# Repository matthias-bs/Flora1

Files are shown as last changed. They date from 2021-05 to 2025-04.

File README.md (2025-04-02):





# flora1 &mdash; Raspberry Pi Irrigation System

flora-1_188x300

## Features
* Plant status monitorig via [Xiaomi Mi Flora Plant Sensor MQTT Client/Daemon](https://github.com/ThomDietrich/miflora-mqtt-daemon)
* Tank low / tank empty status monitoring with XKC-Y25-T12V (Non-Contact Liquid Level Sensor)
* Pump control (12 Volts) with [Infineon BTS621L1](https://www.infineon.com/cms/en/product/power/smart-low-side-high-side-switches/high-side-switches/classic-profet-12v-automotive-smart-high-side-switch/bts621l1-e312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) (Smart Two-Channel High-Side Power Switch)
* Automatic and manual irrigation control with one or two pumps
* Controlling and monitoring via MQTT 

## Dashboard with [IoT MQTT Panel](https://snrlab.in/iot/iot-mqtt-panel-user-guide) (Example)

IoTMQTTPanel_Flora-Control_400x580

## Why is it called _flora1_?

Because _flora2_ is already in the works!

## Notes

### Starting with Linux systemd service

#### Issue

After updating from *Raspbian Buster* to Raspberry Pi OS *Debian Bookworm*, the service wouln't start. The reason was that some code in `lgpio` used for accessing GPIO pins tries to write into the working directory (see https://github.com/gpiozero/gpiozero/issues/1106), which was not permitted.

#### Workaround

* Split WorkingDirectory and RuntimeDirectory (see [09_software/template.service](https://github.com/matthias-bs/Flora1/blob/2-starting-via-linux-systemd-service-fails/09_software/template.service))
  * WorkingDirectory=/var/run/flora/
  * RuntimeDirectory=/opt/flora
* Create `/var/run/flora` at startup (if will not persist if created manually!)
  * See https://serverfault.com/questions/824393/var-run-directory-creation-even-though-service-is-disabled
  * In `/usr/lib/tmpfiles.d/var.conf`:<br>
    add<br>
    `d /var/run/flora 0770 root daemon -`

----

## Disclaimer and Legal

> *Xiaomi* and *Mi Flora* are registered trademarks of *BEIJING XIAOMI TECHNOLOGY CO., LTD.*
>
> This project is a community project not for commercial use.
> The authors will not be held responsible in the event of device failure or withered plants.
>
> This project is in no way affiliated with, authorized, maintained, sponsored or endorsed by *Xiaomi* or any of its affiliates or subsidiaries.

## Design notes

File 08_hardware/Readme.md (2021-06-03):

# flora1 Hardware

Selecting a Raspberry Pi version
---------------------------------
My initial plan was to re-use an old *Raspberry Pi Model B* (which is more than adequate regarding speed and memory), but the WiFi connection via USB dongle proved to be unreliable. Restarting the driver via a script called from a cron-job did not help either.
Moving to a *Raspberry Pi 3 Model A+* solved this issue. This version was selected as a good compromise between power consumption, size, price and processing power.

Connector J4
-------------
Due to the initial plan using a *Raspberry Pi Model B*, a 26-pin header was used. For changing to a *Raspberry Pi 3*, a ribbon cable with a 26-pin-connector on one side and a 40-pin-connector on the other side was used. **It is highly recommended to use a 40-pin header in new designs!**

High Side Driver Infineon BTS621L1
-----------------------------------
The driver works fine, but the device package seems to be outdated (and is not very practical for breadboard designs). For a redesign, I used the [Infineon BTS117](https://www.infineon.com/cms/en/product/power/smart-low-side-high-side-switches/low-side-switches/classic-hitfet-24v/bts117/) *"N channel vertical power FET in Smart SIPMOS® technology"*. The latter is a single channel low-side switch and provides less diagnostic functions, but is available in a handy TO220-3 package. 

Breadboard vs. printed circuit board
-------------------------------------
It's a matter of taste, but next time I would rather design a printed circuit board and have it made by a PCB service. In the original design an *RND 455-00555* prototype board (67.8x86.9mm) by *RND Components* was used. 

Barometric Pressure Sensor connector (J1)
------------------------------------------
For new designs, I prefer a *Bosch BME280* instead of the *NXP MPL115*. The *BME280* provides temperature, humidity and barometric pressure with (in my opinion) excellent specifications.

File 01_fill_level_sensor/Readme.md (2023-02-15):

# flora1 Tank Level Sensors

[DFRobot SEN0204 Non-contact Liquid Level Sensor XKC-Y25-T12V](https://wiki.dfrobot.com/Non-contact_Liquid_Level_Sensor_XKC-Y25-T12V_SKU__SEN0204)

Or use your favourite search engine to find the manual/"datasheet" and a supplier for the sensor **XKC Y25 T12V**. The original manufacturer seems to be hard to find...

XKC_Y25_T12V Front View

XKC_Y25_T12V Front View

XKC_Y25_T12V Back View
(I am using velcro tape to attach the sensors to the tank.)

XKC_Y25_T12V Back View

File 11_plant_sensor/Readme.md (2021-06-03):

# flora1 Plant Sensors

Please refer to https://xiaomi-mi.com/home/user-manuals/ and search for *Huahuacacao Flower Care Smart Monitor* - or use your favourite search engine with the keywords *Mi Flora Plant Sensor* or *Mi Flora Flower Care* for manual/datasheet.

Mi Flora Plant Sensor

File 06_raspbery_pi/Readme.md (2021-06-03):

# flora1 Raspberry Pi

[Raspberry Pi 3 Model A+](https://www.raspberrypi.org/products/raspberry-pi-3-model-a-plus/)

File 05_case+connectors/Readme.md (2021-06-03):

# flora1 Case and Connectors

    | Pos. | Part                                         | Description                        | Comments                         |
    |------|----------------------------------------------|------------------------------------|----------------------------------|
    |    1 | BOPLA EM 238 F                               | Case                               | lots of space for add-ons...     |
    |      | (Series Euromas II, 160 x 120 x 92 mm, IP65) |                                    |                                  |
    | ---- | -------------------------------------------- | ---------------------------------- | -------------------------------- |
    |    2 | Raspberry Pi Sticker                         |                                    | not strictly necessary, but cool |
    | ---- | -------------------------------------------- | ---------------------------------- | -------------------------------- |
    |    3 | GORE PMF 100391 / Wiska EVPS 12 HF           | Vent, M12                          | optional                         |
    |      | (or similar) with M12 Nut                    |                                    |                                  |
    | ---- | -------------------------------------------- | ---------------------------------- | -------------------------------- |
    |    4 | 2x Cable Gland M12 with M12 Nut              | for Power Supply + Pump            |                                  |
    | ---- | -------------------------------------------- | ---------------------------------- | -------------------------------- |
    |    5 | 2x Barrel Jack 2.1mm x 5.5mm with Pigtail    | for Power Supply + Pump            | preferably with sleeve           |
    | ---- | -------------------------------------------- | ---------------------------------- | -------------------------------- |
    |    6 | 2x Pöppelmann Kapsto GPN 305 GV 12           | Sealing Plugs for Barrel Jacks     | optional                         |
    | ---- | -------------------------------------------- | ---------------------------------- | -------------------------------- |
    |    7 | 2x Lumberg Quicklock 0270-04 /               | Quicklock chassis sockets, IP67,   |                                  |
    |      | Lutronic Quicklock 2320 04 T12CB100          | Size 12 - for Fill Level Inputs    |                                  |
    | ---- | -------------------------------------------- | ---------------------------------- | -------------------------------- |
    |    8 | 2x Lumberg Quicklock 0250-04 /               | Quicklock plug with locking latch, |                                  |
    |      | Lutronic 2350 04 T06CB T                     | IP67, Size 12 - for Level Sensors  |                                  |
    |------|----------------------------------------------|------------------------------------|----------------------------------|

flora-1_378x600      flora-2_378x600

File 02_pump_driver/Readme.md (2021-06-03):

# flora1 Pump Driver

[Infineon BTS621L1](https://www.infineon.com/cms/en/product/power/smart-low-side-high-side-switches/high-side-switches/classic-profet-12v-automotive-smart-high-side-switch/bts621l1-e312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) "High side power switch with integrated vertical power FET".
The TO220-7 package version seems to be discontinued.

For a redesign, I used the [Infineon BTS117](https://www.infineon.com/cms/en/product/power/smart-low-side-high-side-switches/low-side-switches/classic-hitfet-24v/bts117/) "N channel vertical power FET in Smart SIPMOS® technology". The latter is a single channel low-side switch and provides less diagnostic functions.

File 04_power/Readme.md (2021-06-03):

# flora1 Power

**Note: Please ensure that your AC-DC-adaptor's specifications (IP class) meet your environmental conditions!** 

AC-DC Wall mount adaptor 12V/3A: [Mean Well GS36E12-P1J](https://www.meanwell-web.com/en-gb/ac-dc-wall-mount-adaptor-output-12vdc-at-3a-input-gs36e12--p1j) **_For indoor use only!_** 

DC-DC-Converter 6-40V to 5V/3A: [REG5V3A](https://www.berrybase.de/en/raspberry-pi/raspberry-pi-computer/power-supply/built-in-industrial-power-supply-modules/netzteilmodul-6-40v-5v/3a-mit-2x-usb-ausgang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)

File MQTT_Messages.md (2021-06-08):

# flora1 MQTT Messages

```
MQTT subscriptions:
     <base_topic_sensors>/<sensors>{}      (JSON encoded data from Miflora MQTT Daemon)
     <base_topic>/man_report_cmd           (-)
     <base_topic>/man_irr_cmd              (1|2)                         1: pump #1 / 2: pump #2
     <base_topic>/man_irr_duration_ctrl    (<seconds>)
     <base_topic>/auto_report_ctrl         (0|1)
     <base_topic>/auto_irr_ctrl            (0|1)

MQTT publications:
     <base_topic>/status                   (online|offline|idle|dead$)
     <base_topic>/man_irr_stat             (0|1)
     <base_topic>/man_irr_duration_stat    (<seconds>
     <base_topic>/auto_report_stat         (0|1)
     <base_topic>/auto_irr_stat            (0|1)
     <base_topic>/tank                     (0|1|2)                        0: empty / 1: low / 2: o.k.

$ via LWT
```

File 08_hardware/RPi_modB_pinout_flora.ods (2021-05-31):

Raspberry Pi Model B Port 1 Pinout
MPL115_VDD |  | 3V3 | 1 | 2 | +5V
 | I2C_SDA | GPIO2 | 3 | 4 | +5V |  | XKC-Y25-NPN_VCC
 | I2C_SCL | GPIO3 | 5 | 6 | GND |  | MPL115_GND
 |  | GPIO4 | 7 | 8 | GPIO14 | UART_TXD
PUMP_GND |  | GND | 9 | 10 | GPIO15 | UART_RXD
 | UART_RTS | GPIO17 | 11 | 12 | GPIO18 | PWM | (SENSOR_PWR)
PUMP_OUT |  | GPIO27 | 13 | 14 | GND |  | XKC-Y25-NPN_GND
PUMP_STATUS |  | GPIO22 | 15 | 16 | GPIO23 |  | XKC-Y25-NPN_LOW
 |  | 3V3 | 17 | 18 | GPIO24 |  | XKC-Y25-NPN_EMPTY
MPL115_PWR | SPI_MOSI | GPIO10 | 19 | 20 | GND
MPL115_SDO | SPI_MISO | GPIO9 | 21 | 22 | GPIO25
MPL115_SCK | SPI_CLK | GPIO11 | 23 | 24 | GPIO8 | SPI_CE0 | MPL115_CSN
 |  | GND | 25 | 26 | GPIO7 | SPI_CE1

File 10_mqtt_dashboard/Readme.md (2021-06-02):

# Set up *IoT MQTT Panel* from configuration file

You can either edit the provided [JSON configuration file](https://github.com/matthias-bs/Flora1/blob/main/10_mqtt_dashboard/IoTMQTTPanel_Example.json) before importing it or import it as-is and make the required changes in *IoT MQTT Panel*. Don't forget to add the broker's certificate if using Secure MQTT! (in the App: *Connections -> Edit Connections: Certificate path*.)

The dashboard will look like this:
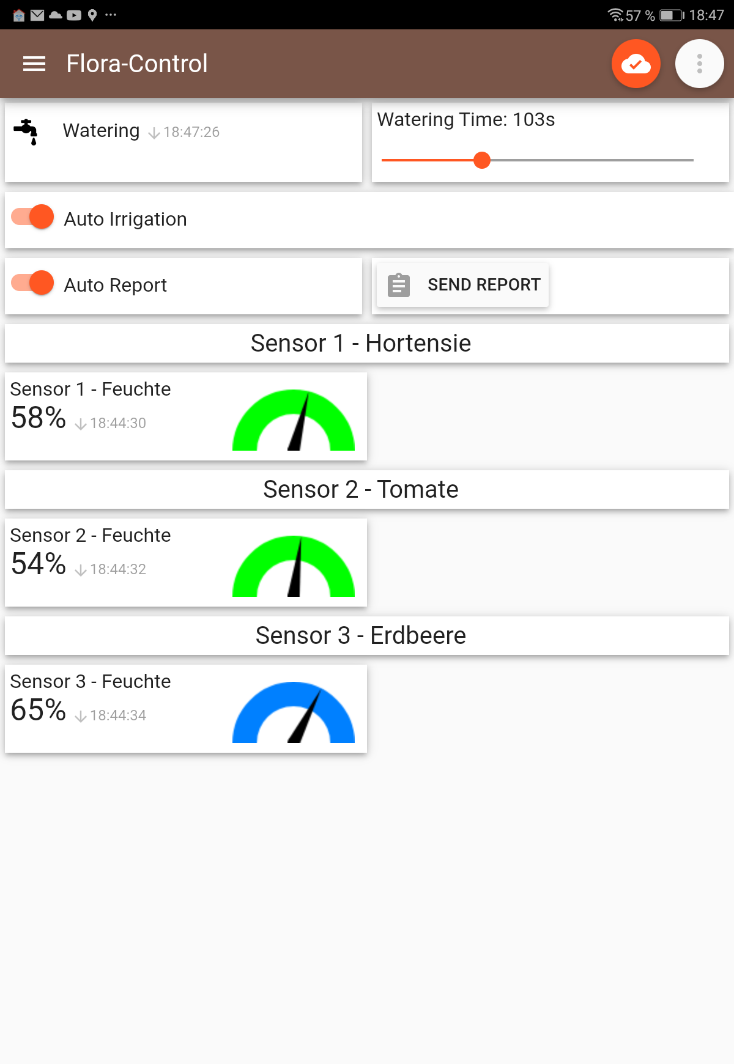
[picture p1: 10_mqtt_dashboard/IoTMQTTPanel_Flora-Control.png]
IoTMQTTPanel - Flora-Control


----
**Install _IoT MQTT Panel_ on your Android device**
  
  see [IoT MQTT Panel](https://snrlab.in/iot/iot-mqtt-panel-user-guide)

----
**Editing [IoTMQTTPanel_Example.json](https://github.com/matthias-bs/Flora1/blob/main/10_mqtt_dashboard/IoTMQTTPanel_Example.json)**

At the beginning, replace the dummy IP address *123.345.678* and port *8883* by your MQTT broker's IP address/hostname and port, change *Your_Client_ID* and *Your_MQTT_Connection* as needed:
```
[...]
"connections":[{"autoConnect":true,"host":"123.345.678","port":8883,"clientId":"Your_Client_ID","connectionName":"Your_MQTT_Connection"
[...]
```

At the end, change *Your_Username* and *Your_Password* as needed:
```
[...]
"username":"Your_Username","password":"Your_Password"
[...]
```

----
**Changing example configuration in _IoT MQTT Panel_**

**Edit _Connection Name_, _Client ID_ and _Broker_:**
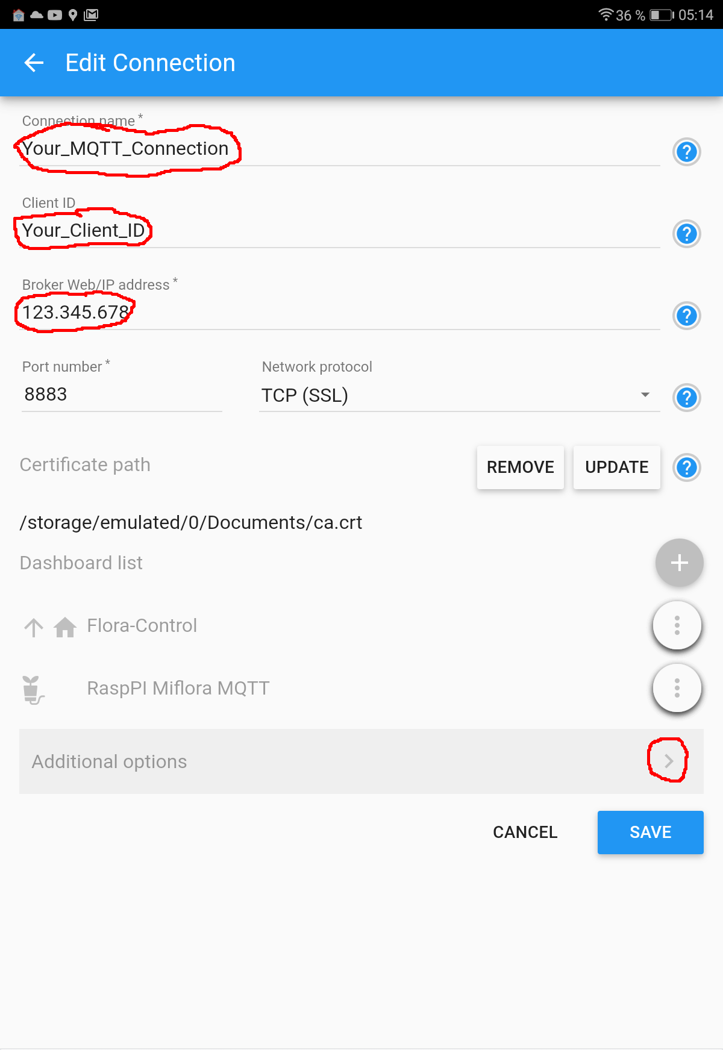
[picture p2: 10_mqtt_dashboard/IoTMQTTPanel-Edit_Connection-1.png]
Edit Connection Name, Client ID and Broker


**Edit _Username_ and _Password_:**
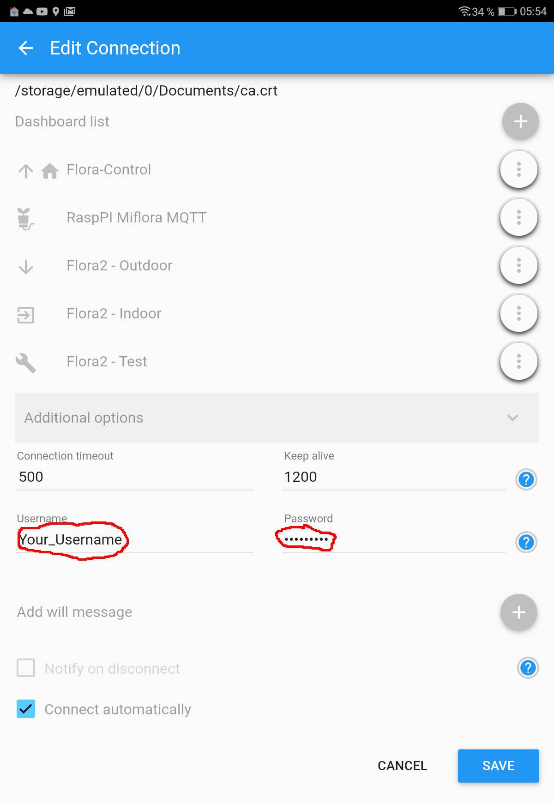
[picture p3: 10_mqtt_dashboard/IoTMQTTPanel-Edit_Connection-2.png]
Edit Username and Password


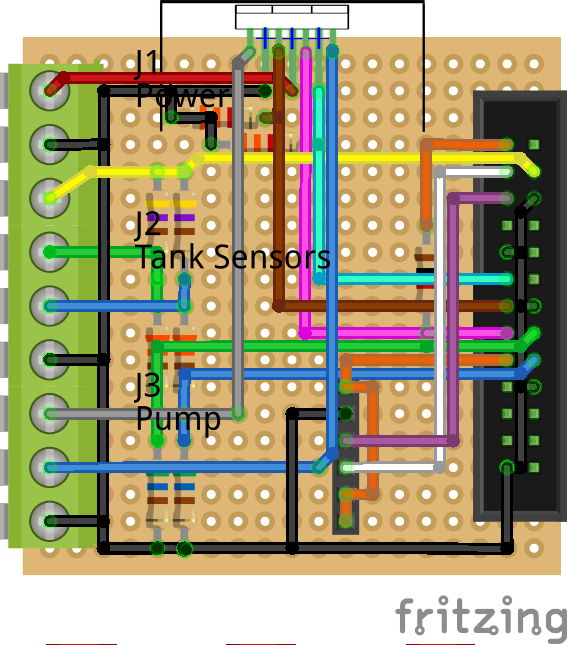
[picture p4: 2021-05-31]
08_hardware/flora_breadboard_rev05_board.png

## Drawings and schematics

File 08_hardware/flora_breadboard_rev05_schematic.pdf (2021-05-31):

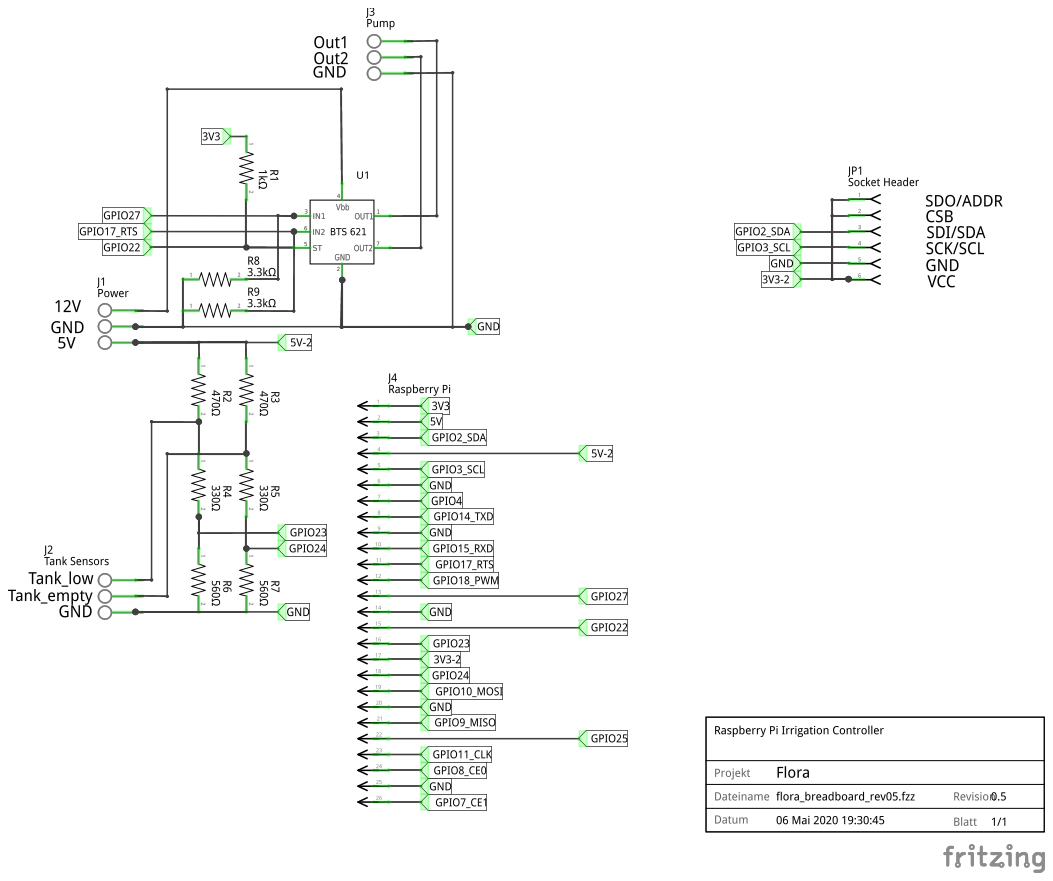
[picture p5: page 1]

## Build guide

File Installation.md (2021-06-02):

# flora1 Software Installation

----
**Overview**

1. Raspberry Pi OS Installation
2. Mosquitto MQTT-Broker Installation and Configuration
3. miflora-mqtt-daemon Installation
4. Optional: Configure Raspberry Pi with static IP address
5. Optional: Set up port forwarding in your router to access your MQTT broker from internet
6. flora1 Installation and Configuration

----
**1. Raspberry Pi OS Installation / Update**

Please refer to https://www.raspberrypi.org/software/.

If you want to use an existing installation, an update might be a good idea:
```
$ sudo apt-get update
$ sudo apt-get upgrade
```
----
**2. Mosquitto MQTT-Broker Installation and Configuration**

Please refer to https://github.com/eclipse/mosquitto for details.

Installation:
```
$ sudo apt-get install -y mosquitto mosquitto-clients
```

Excellent resources on MQTT and Mosquitto:
* http://www.steves-internet-guide.com
* https://www.hivemq.com/mqtt-essentials/

How to set up security mechanisms:
* http://www.steves-internet-guide.com/mqtt-security-mechanisms/
* http://www.steves-internet-guide.com/mqtt-username-password-example/
* http://www.steves-internet-guide.com/mosquitto-tls/

The [MQTT-Explorer](https://github.com/thomasnordquist/MQTT-Explorer) is very useful for testing.

----
**3. miflora-mqtt-daemon Installation**

Please refer to https://github.com/ThomDietrich/miflora-mqtt-daemon.

For compatibility with Flora1, set `reporting_method = mqtt-json` in the **miflora-mqtt-daemon** `config.ini`.

----
**4. Optional: Configure Raspberry Pi with static IP address**

Example `/etc/dhcpcd.conf`:
```
[...]
interface wlan0
static ip_address=192.168.0.10/24
static routers=192.168.0.1
static domain_name_servers=192.168.0.1
```
In this example, the Raspberry gets the private IP Address `192.168.0.10` and the router/DNS has the private IP address ```192.168.0.1```.

----
**5. Optional: Set up port forwarding in your router to access your MQTT broker from the Internet**

***Please refer to your router's documentation and make sure to maintain security!***
***It is highly recommended to allow only Secure MQTT (MQTT over TLS, port 8883) forwarding.***

----
**6. flora1 Installation and Configuration**

Install Python 3 (should already been done in step 3):
```
$ sudo apt install git python3 python3-pip
```

Copy all source files from https://github.com/matthias-bs/Flora1/tree/main/09_software to `/opt/flora`.
```
$ cd /opt/flora
$ sudo cp config.ini.dist config.ini
```
Edit `config.ini` as required. (e.g. ```sudo nano config.ini```) 

Flora1 needs access to GPIO ports to monitor the tank level and and to control the pump.

```$ sudo adduser daemon gpio```

Test your setup / ```config.ini```:

```python3 flora.py```

If everything works as desired: Congratulations!

Now set up flora to run in daemon mode:
```
$ sudo cp /opt/flora/template.service /etc/systemd/system/flora.service
$ sudo systemctl daemon-reload
$ sudo systemctl start flora.service
$ sudo systemctl status flora.service
$ sudo systemctl enable flora.service
```

If needed, check status/error messages in ```/var/log/syslog```.

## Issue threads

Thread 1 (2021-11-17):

Alert handling for empty tank does not work properly

matthias-bs, 2021-11-17:
**Describe the bug**
Email status reports due to **tank empty alert** are sent repeatedly in short intervals , even if alert handling has been set as follows in _config.ini_:
```
# alert handling modes:
[...]
# 1 - immediate alert, only once
[...]
e_tank_empty = 1
```
A similar issue was never observed for **tank low alert** with the same configuration.

**To Reproduce**
Set `e_tank_empty = 1` in _config.ini_. Drain the tank until empty level is detected.

**Expected behavior**
Email status report due to empty tank should be sent only once.

**Additional context**
Outside temperatures around 7-9°C might have influence on the level sensor's trigger level.

matthias-bs, 2021-11-17:
Possible cause: Tank level sensor output might toggle between active and inactive state.

matthias-bs, 2025-04-02:
Alert mechanism has been removed.

Closed 2025-04-02.

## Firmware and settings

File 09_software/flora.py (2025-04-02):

#!/usr/bin/env python3
# -*- coding: utf-8 -*-

###############################################################################
# flora.py
# Plant monitoring and irrigation system using Raspberry Pi
#
# - based on data provided by Mi Flora Plant Sensor MQTT Client/Daemon
# - controls water pump for irrigation
# - monitors water tank - two levels, low and empty
# - provides control/status via MQTT
#
# MQTT subscriptions:
#     <base_topic_sensors>/<sensors>{}      (JSON encoded data)
#     <base_topic>/man_irr_cmd              (1|2)
#     <base_topic>/man_irr_duration_ctrl    (<seconds>)
#     <base_topic>/auto_irr_ctrl            (0|1)
#
# MQTT publications:
#     <base_topic>/status                   (online|offline|idle|dead$)
#     <base_topic>/man_irr_stat             (0|1)
#     <base_topic>/man_irr_duration_stat    (<seconds>)
#     <base_topic>/auto_irr_stat            (0|1)
#     <base_topic>/tank                     (0|1|2)
#
# $ via LWT
#
# created: 02/2020
#
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
# History:
#
# 20200226 Tank level sensor input working
# 20200302 Config file reading implemented
# 20200304 MQTT client for plant sensor data working
# 20200309 E-mail report implemented, pump control via MQTT message working
# 20200325 Sending e-mail report based on sensor/plant data implemented
# 20200421 Specific irrigation time for automatic/manual mode added
#          MQTT feedback messages for manual irrigation time setting added
#          Handling of sensor time-out added
# 20200428 Added switching auto reporting and auto irrigation on/off via MQTT
# 20200502 Rev. 1.0, Initial release
# 20200504 Added night mode
# 20210105 Fixed manual irrigation
#          Messages were queued while irrigation was already in progress,
#          which led to multiple irrigation cycles where only one was desired.
#          Added message 'man_irrigation_status'
# 20210106 Code cleanup
#          Added tank object as parameter to Pump class constructor -
#          the mapping between pump and tank will never change during run time
# 20210116 Major refactoring and switch to object oriented implementation
#          Functional improvement of E-mail reporting
# 20210117 Split source file into multiple modules
#          Replaced set-/get-methods by properties
# 20210118 Renamed MQTT topics
# 20210602 Added MQTT status message and last will
#          Added MQTT tank message
# 20210608 Added support of 2nd pump
# 20230204 Coding style improvements and bugfixes (with pylint)
# 20250401 Removed auto_report/man_report and alert handling
# 20250401 Removed email support, added JSON output for MQTT
#          Added publish_discovery_sensor() for Home Assistant
#
# To Do:
# - compare light value against daily average
# - add humidity/barometric pressure sensor
#
###############################################################################

import locale
import sys
import argparse
import os.path
import json
import ssl
from time import sleep
from configparser import ConfigParser
import paho.mqtt.client as mqtt
from colorama import init as colorama_init
from colorama import Fore, Style
from ppretty import ppretty #for debugging only

# Flora specific modules
from settings import Settings, DEBUG, VERBOSITY, PROJECT_NAME, PROJECT_VERSION,\
                     PROJECT_BUILD, PROJECT_URL, GPIO_TANK_SENS_LOW, GPIO_TANK_SENS_EMPTY,\
                     GPIO_PUMP_POWER, GPIO_PUMP_STATUS, PROCESSING_PERIOD, MESSAGE_TIMEOUT,\
                     BATT_LOW, PUMP_BUSY_MAN
from print_line import print_line, sd_notifier
from gpio import GPIO
from sensor import Sensor
from tank import Tank
from pump import Pump
from irrigation import Irrigation
from report import Report

# Options expected (mandatory!) in each sensor-/plant-data section of the config-file
OPTIONS = [
    'name',
    'temp_min',
    'temp_max',
    'cond_min',
    'cond_max',
    'moist_min',
    'moist_lo',
    'moist_hi',
    'moist_max',
    'light_min',
    'light_irr',
    'light_max'
]


#############################################################################################
# MQTT - Eclipse Paho Setup
#############################################################################################
def mqtt_init(cfg):
    """
    Init MQTT client and connect to MQTT broker

    Parameters:
        cfg (ConfigParser): config file parser
    """

    # MQTT Connection
    print_line('Connecting to MQTT broker -->')
    client = mqtt.Client()
    client.on_connect = mqtt_on_connect

    if cfg['MQTT'].getboolean('tls', False):
    # According to the docs, setting PROTOCOL_SSLv23 "Selects the highest protocol version
    # that both the client and server support. Despite the name, this option can select
    # 'TLS' protocols as well as 'SSL'" - so this seems like a resonable default
        client.tls_set(
            ca_certs=cfg['MQTT'].get('tls_ca_cert', None),
            keyfile=cfg['MQTT'].get('tls_keyfile', None),
            certfile=cfg['MQTT'].get('tls_certfile', None),
            tls_version=ssl.PROTOCOL_SSLv23
        )

    # Set 'Last Will and Testament"
    client.will_set(settings.base_topic_flora + '/status', 'dead', qos=1, retain=True)

    if cfg['MQTT'].get('username'):
        client.username_pw_set(cfg['MQTT'].get('username'),
                                    cfg['MQTT'].get('password', None))
    try:
        client.connect(cfg['MQTT'].get('hostname', 'localhost'),
                       port=cfg['MQTT'].getint('port', 1883),
                       keepalive=cfg['MQTT'].getint('keepalive', 60))
    except: # pylint: disable=bare-except
        print_line('MQTT connection error. Please check your settings in the ' +\
                'configuration file "config.ini"', error=True, sd_notify=True)
        sys.exit(1)

    return client



def mqtt_setup_messages(client, mqtt_settings, mysensors):
    """
    Subscribe to MQTT topics and set up message callbacks

    Parameters:
        client (Client): MQTT Client
    """
    # Subscribe to flora control MQTT topics
    for topic in ['man_irr_cmd', 'man_irr_duration_ctrl', 'auto_irr_ctrl']:
        print_line('Subscribing to MQTT topic ' + mqtt_settings.base_topic_flora + '/' + topic,
                   console=True, sd_notify=True)
        client.subscribe(mqtt_settings.base_topic_flora + '/' + topic, qos=2)

    # Subscribe all MQTT sensor topics, e.g. "miflora-mqtt-daemon/appletree/moisture"
    for _sensor in mysensors:
        print_line('Subscribing to MQTT topic ' + mqtt_settings.base_topic_sensors + '/' + _sensor,
                console=True, sd_notify=True)
        client.subscribe(mqtt_settings.base_topic_sensors + '/' + _sensor)

    # Set topic specific message handlers
    client.message_callback_add(mqtt_settings.base_topic_flora + '/man_irr_cmd', mqtt_man_irr_cmd)
    client.message_callback_add(mqtt_settings.base_topic_flora + '/man_irr_duration_ctrl', mqtt_man_irr_duration_ctrl)
    client.message_callback_add(mqtt_settings.base_topic_flora + '/auto_irr_ctrl', mqtt_auto_irr_ctrl)

    # Message handler for reception of all other subsribed topics
    client.on_message = mqtt_on_message

def publish_discovery_sensor(name):
    """
    Publish MQTT discovery messages for Home Assistant
    
    Parameters:
        name (string): sensor name (same as data topic)
    """
    state_topic = f"{settings.base_topic_flora}/{name}"
    sensor_name = f"{settings.base_topic_flora}_{name}"
    
    if name == "tank":
        adv_sensors = [
            {"name": f"{sensor_name}_int", "stat_t": f"{settings.base_topic_flora}/tank", "dev_cla": "enum", "val_tpl": "{{ value }}", "unit_of_meas": ""},
            {"name": f"{sensor_name}_str", "stat_t": f"{settings.base_topic_flora}/system", "dev_cla": "enum", "val_tpl": "{{ value_json.tank }}", "unit_of_meas": ""}
        ]
    else:
        adv_sensors = [
            {"name": f"{name}_battery", "stat_t": f"{state_topic}", "dev_cla": "battery", "val_tpl": "{{ value_json.battery | int }}", "unit_of_meas": "%"},
            {"name": f"{name}_brightness", "stat_t": f"{state_topic}", "dev_cla": "illuminance", "val_tpl": "{{ value_json.light | int }}", "unit_of_meas": "lx"},
            {"name": f"{name}_moisture", "stat_t": f"{state_topic}", "dev_cla": "moisture", "val_tpl": "{{ value_json.moisture | int }}", "unit_of_meas": "%"},        
            {"name": f"{name}_temperature", "stat_t": f"{state_topic}", "dev_cla": "temperature", "val_tpl": "{{ value_json.temperature | float }}", "unit_of_meas": "°C"},
            {"name": f"{name}_conductivity", "stat_t": f"{state_topic}", "dev_cla": "conductivity", "val_tpl": "{{ value_json.conductivity | int }}", "unit_of_meas": "µS/cm"}
        ]

    for adv_sensor in adv_sensors:
        discovery_topic = f"homeassistant/sensor/{adv_sensor['name']}/config"
        discovery_payload = {
            "name": adv_sensor["name"],
            "stat_t": adv_sensor["stat_t"],
            "val_tpl": adv_sensor["val_tpl"],
            "unit_of_meas": adv_sensor["unit_of_meas"],
            "dev_cla": adv_sensor["dev_cla"],
            "uniq_id": adv_sensor["name"],
            "dev": {
                "identifiers": ["plant_sensor"],
                "name": "Flora2",
            }
        }
        mqtt_client.publish(discovery_topic, json.dumps(discovery_payload).encode("utf-8"))

#############################################################################################
# MQTT - Eclipse Paho callbacks - http://www.eclipse.org/paho/clients/python/docs/#callbacks
#############################################################################################
def mqtt_on_connect(_client, _userdata, _flags, rc):
    """
    MQTT client connect initialization callback function

    Parameters:
        client: client instance for this callback
        userdata: private user data as set in Client() or user_data_set()
        flags: response flags sent by the broker
        rc: return code - connection result
    """
    if rc == 0:
        print_line('<-- MQTT connection established', console=True, sd_notify=True)
    else:
        print_line('Connection error with result code {} - {}'.format(str(rc),
                   mqtt.connack_string(rc)), error=True)
        # kill main thread
        os._exit(1) # pylint: disable=protected-access

    # Set up MQTT message subscription and handlers
    mqtt_setup_messages(mqtt_client, settings, sensors)


def mqtt_man_irr_cmd(_client, _userdata, msg):
    """
    Run irrigation for <irr_duration> seconds.

    This is an MQTT message callback function

    Parameters:
        client: client instance for this callback
        userdata: private user data as set in Client() or user_data_set()
        msg: an instance of MQTTMessage. This is a class with members topic, payload, qos, retain
    """
    val = int(msg.payload)
    print_line('MQTT message "man_irr_cmd({})" received'.format(val), console=True, sd_notify=True)
    if (val == 1) or (val == 2):
        idx = val - 1
        if pumps[idx].busy:
            print_line('Pump #{} already busy ({:s}), ignoring request'
                       .format(val, "manual" if (pumps[idx].busy == PUMP_BUSY_MAN) else "auto"),
                       console=True, sd_notify=True)
            return

        mqtt_client.publish(settings.base_topic_flora + '/man_irr_stat', payload=str(val), qos = 1)
        pumps[idx].busy = PUMP_BUSY_MAN


def mqtt_man_irr_duration_ctrl(client, _userdata, msg):
    """
    Set manual irrigation duration (<irr_duration_man>)

    This is an MQTT message callback function

    In this case, MQTT Dash sends the value as string/byte array.
    (b'65' means integer value 65)
    The response message contains the original payload, which
    is used by MQTT Dash to set the visual state.

    Parameters:
        client: client instance for this callback
        userdata: private user data as set in Client() or user_data_set()
        msg: an instance of MQTTMessage. This is a class with members topic, payload, qos, retain
    """
    settings.irr_duration_man = int(msg.payload)

    print_line('MQTT message "man_irr_duration_ctrl({})" received'.format(settings.irr_duration_man),
               console=True, sd_notify=True)
    client.publish(settings.base_topic_flora + '/man_irr_duration_stat', msg.payload)


def mqtt_auto_irr_ctrl(client, _userdata, msg):
    """
    Switch auto irrigation on/off

    This is an MQTT message callback function

    In this case, MQTT Dash sends the value as string/byte array.
    (b'0'/b'1' means integer value 0/1)
    The response message contains the original payload, which
    is used by MQTT Dash to set the visual state.

    Parameters:
        client: client instance for this callback
        userdata: private user data as set in Client() or user_data_set()
        msg: an instance of MQTTMessage. This is a class with members topic, payload, qos, retain
    """
    settings.auto_irrigation = int(msg.payload)

    print_line('MQTT message "auto_irr_ctrl({})" received'.format(settings.auto_irrigation),
               console=True, sd_notify=True)
    client.publish(settings.base_topic_flora + '/auto_irr_stat', msg.payload)


def mqtt_on_message(_client, _userdata, msg):
    """
    Handle all other MQTT messages, i.e. those with sensor data.

    This is an MQTT message callback function.

    Parameters:
        client: client instance for this callback
        userdata: private user data as set in Client() or user_data_set()
        msg: an instance of MQTTMessage. This is a class with members topic, payload, qos, retain
    """
    _, _sensor = msg.topic.split('/')

    # Convert JSON ecoded data to dictionary
    message = json.loads(msg.payload.decode('utf-8'))

    if VERBOSITY > 1:
        print_line('MQTT message from {}: {}'.format(_sensor, message))

    # Discard data if moisture value suddenly drops to zero
    if (float(message['moisture']) == 0) and (sensors[_sensor].moist > 5):
        return

    sensors[_sensor].update_sensor(
        float(message['temperature']),
        int(message['conductivity']),
        int(message['moisture']),
        int(message['light']),
        int(message['battery'])
    )


###############################################################################
# Init
###############################################################################

if __name__ == '__main__':

    locale.setlocale(locale.LC_ALL, 'de_DE.UTF8')

    # Argparse
    # https://pymotw.com/3/configparser/
    # https://stackoverflow.com/questions/22068050/iterate-over-sections-in-a-config-file
    parser = argparse.ArgumentParser(description=PROJECT_NAME)
    parser.add_argument('--config_dir',
                        help='set directory where config.ini is located',
                        default=sys.path[0])
    parse_args = parser.parse_args()

    # Intro
    colorama_init()
    print(Fore.GREEN + Style.BRIGHT)
    print(PROJECT_NAME)
    print(PROJECT_VERSION)
    print(PROJECT_BUILD)
    print('Source:', PROJECT_URL)
    print(Style.RESET_ALL)

    # Load configuration file
    config_dir = parse_args.config_dir
    config = ConfigParser(delimiters=('=', ), inline_comment_prefixes=('#', ))
    config.optionxform = str
    config.read([os.path.join(config_dir, 'config.ini.dist'),
                os.path.join(config_dir, 'config.ini')])

    # Set BCM pin addressing mode
    GPIO.setmode(GPIO.BCM)

    # Generate tank object (fill level sensors)
    tank = Tank(GPIO_TANK_SENS_LOW, GPIO_TANK_SENS_EMPTY)

    # Generate pump objects
    pumps = [None, None]
    for i in range(2):
        pumps[i] = Pump(GPIO_PUMP_POWER[i], GPIO_PUMP_STATUS[i], tank)

    # Get configuration data from section [Daemon]
    daemon_enabled = config['Daemon'].getboolean('enabled', 'yes')

    # Get more configuration data from section [General]
    period = config['General'].getint('processing_period', PROCESSING_PERIOD)
    batt_low = config['General'].getint('batt_low', 5)

    # Get list of sensor names from config file
    sensor_list = config['MQTT'].get('sensors')
    sensor_list = sensor_list.split(',')

    if sensor_list == []:
        print_line('No sensors found in the configuration file "config.ini" in the [MQTT] section.',
                error=True, sd_notify=True)
        sys.exit(1)

    # Get sensor timeout from config file
    sensor_timeout = config['MQTT'].getint('message_timeout', MESSAGE_TIMEOUT)

    # Get sensor battery limit from config file
    sensor_batt_min = config['General'].getint('batt_low', BATT_LOW)

    # Create a dictionary of Sensor objects
    sensors = {}
    for sensor in sensor_list:
        sensors[sensor] = Sensor(sensor, sensor_timeout, sensor_batt_min)
        # check if config file contains a section for this sensor
        if not config.has_section(sensor):
            print_line('The configuration file "config.ini" has a sensor named {} \
                        in the [MQTT] section,'
                    .format(sensor), error=True, sd_notify=True)
            print_line('but no plant data has provided in a section named accordingly.',
                    error=True, sd_notify=True)
            sys.exit(1)

    # Read all plant data from the section (section name = sensor name)
    for sensor in sensors:
        for option in OPTIONS:
            if not config.has_option(sensor, option):
                print_line('The configuration file "config.ini" has a section "[' + sensor + ']",',
                        error=True, sd_notify=True)
                print_line('but the mandatory key "' + option + '" is missing.',
                        error=True, sd_notify=True)
                sys.exit(1)

        sensors[sensor].init_plant(
            plant     = config[sensor].get('name'),
            pump      = config[sensor].getint('pump'),
            temp_min  = config[sensor].getfloat('temp_min'),
            temp_max  = config[sensor].getfloat('temp_max'),
            cond_min  = config[sensor].getint('cond_min'),
            cond_max  = config[sensor].getint('cond_max'),
            moist_min = config[sensor].getint('moist_min'),
            moist_lo  = config[sensor].getint('moist_lo'),
            moist_hi  = config[sensor].getint('moist_hi'),
            moist_max = config[sensor].getint('moist_max'),
            light_min = config[sensor].getint('light_min'),
            light_irr = config[sensor].getint('light_irr'),
            light_max = config[sensor].getint('light_max')
        )

    # Initialize settings
    settings = Settings(config)

    # Initialize irrigation
    irrigation = Irrigation()

    # Init MQTT client
    mqtt_client = mqtt_init(config)

    # Start MQTT network handler loop
    mqtt_client.loop_start()

    # Notify syslogd that we are up and running
    sd_notifier.notify('READY=1')

    mqtt_client.publish(settings.base_topic_flora + '/status', "online",
                        qos=1, retain=True)

    # Wait until MQTT data is valid (this may take a while...)
    print_line('Waiting for MQTT sensor data -->',
               console=True, sd_notify=True)

    for sensor in sensors:
        while not sensors[sensor].valid:
            sleep(1)
        if VERBOSITY > 1:
            print_line(sensor + ' ready!', console=True, sd_notify=True)

    print_line('<-- Initial reception of MQTT sensor data succeeded.',
               console=True, sd_notify=True)

    #for sensor in sensors:
    #    publish_discovery_sensor(sensor.name)
    publish_discovery_sensor("tank")

    if DEBUG:
        print_line("---------------------")
        print_line("Settings:")
        print_line("---------------------")
        print_line(ppretty(settings, indent='    ', width=40, seq_length=40,
                           show_protected=True, show_static=True, show_properties=True, show_address=True),
                   console=True, sd_notify=True)

    if DEBUG:
        print_line("---------------------")
        print_line("Sensors: {}".format(sensor_list))
        print_line("---------------------")
        print_line(ppretty(sensors, indent='    ', width=40, seq_length=40,
                           show_protected=True, show_static=True, show_properties=True, show_address=True),
                   console=True, sd_notify=True)

    if VERBOSITY > 0:
        print_line("-----------------------------------------")
        print_line("Starting Main Execution Loop.")
        print_line("-----------------------------------------")


    ###############################################################################
    # Main execution loop
    ###############################################################################
    while True:
        # Execute manual irrigation (if requested)
        irrigation.man_irrigation(settings, mqtt_client, pumps)

        # Execute automatic irrigation
        if settings.auto_irrigation:
            settings.irr_scheduled = irrigation.auto_irrigation(settings, sensors, pumps)

        # Send system settings & status via MQTT
        report = Report(settings, sensors, pumps, tank)
        system = report.gen_report()
        del report
        mqtt_client.publish(settings.base_topic_flora + '/system', system, qos = 1, retain=True)

        # Publish status flags/values
        mqtt_client.publish(settings.base_topic_flora + '/status', "online", qos=1, retain=True)
        mqtt_client.publish(settings.base_topic_flora + '/auto_irr_stat', payload=str(settings.auto_irrigation), qos=1, retain=True)
        mqtt_client.publish(settings.base_topic_flora + '/man_irr_duration_stat', payload=str(settings.irr_duration_man), qos=1, retain=True)
        mqtt_client.publish(settings.base_topic_flora + '/man_irr_stat', payload=str(0), qos = 1)
        mqtt_client.publish(settings.base_topic_flora + '/tank', str(tank.status), qos = 1, retain=True)
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

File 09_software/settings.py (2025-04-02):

"""Provide default settings and user defined settings from the configuration file"""
###############################################################################
# settings.py
#
# This module provides constants as default application settings
# and the class Settings which mostly provides attributes set
# from the configuration file.
#
# It is higly recommended to leave the constants as-is and to
# modify config.ini instead!!!
#
#
# created: 01/2021
#
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
# History:
#
# 20210117 Extracted from flora.py
# 20210602 Added PROJECT_BUILD
# 20210608 Added support of 2nd pump
# 20221010 Fixed initialization of irr_rest
# 20230204 Coding style improvements (with pylint)
# 20250401 Removed auto_report and alerts settings
#
# To Do:
# -
#
###############################################################################


###############################################################################
# Constants
###############################################################################
DEBUG               = False
VERBOSITY           = 1

PROJECT_NAME        = 'flora'
PROJECT_VERSION     = 'V3.0.0'
PROJECT_BUILD       = '20250401'
PROJECT_URL         = 'https://github.com/matthias-bs/Flora1'

GPIO_TANK_SENS_LOW  = 23
GPIO_TANK_SENS_EMPTY = 24
GPIO_PUMP_POWER     = [17, 27]
GPIO_PUMP_STATUS    = [22, 22]

PUMP_BUSY_MAN       = 1
PUMP_BUSY_AUTO      = 2

# Config defaults
PROCESSING_PERIOD   = 300
MESSAGE_TIMEOUT     = 900
NIGHT_BEGIN         = "24:00"
NIGHT_END           = "00:00"
AUTO_IRRIGATION     = 1
IRR_DURATION_AUTO   = 120
IRR_DURATION_MAN    = 60
IRR_REST            = 7200
BATT_LOW            = 5

###############################################################################
# Settings class - Global settings from config file, MQTT messages and others
###############################################################################
class Settings:
    """Global settings from config file"""
    # pylint: disable=too-many-instance-attributes
    # pylint: disable=too-few-public-methods
    def __init__(self, config):
        self.irr_scheduled = [False, False]
        self.auto_irrigation = config['General'].getint('auto_irrigation', AUTO_IRRIGATION)
        self.irr_duration_auto1 = config['General'].getint('irrigation_duration_auto1',
                                                           IRR_DURATION_AUTO)
        self.irr_duration_auto2 = config['General'].getint('irrigation_duration_auto2',
                                                           IRR_DURATION_AUTO)
        self.irr_duration_man = config['General'].getint('irrigation_duration_man',
                                                         IRR_DURATION_MAN)
        self.irr_rest = config['General'].getint('irrigation_rest', IRR_REST)
        self.base_topic_sensors = config['MQTT'].get('base_topic_sensors',
                                                     'miflora-mqtt-daemon').lower()
        self.base_topic_flora = config['MQTT'].get('base_topic_flora',
                                                   'flora').lower()
        night_begin = config['General'].get('night_begin', NIGHT_BEGIN)
        night_end = config['General'].get('night_end', NIGHT_END)
        night_begin_hr, night_begin_min = night_begin.split(':')
        night_end_hr, night_end_min = night_end.split(':')
        self.night_begin_hr = int(night_begin_hr)
        self.night_begin_min = int(night_begin_min)
        self.night_end_hr = int(night_end_hr)
        self.night_end_min = int(night_end_min)

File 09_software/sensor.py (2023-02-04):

"""Store and check plant sensor values"""
###############################################################################
# sensor.py
#
# This module provides the Sensor class
#
# - stores sensor data
# - stores plant data (i.e. limits for environmental conditions)
# - compares sensor data with plant data
# - allows to check low battery, sensor data timeout and sensor data valid
#
# created: 01/2021
#
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
# History:
#
# 20210117 Extracted from flora.py
# 20210608 Added support of 2nd pump
# 20230204 Coding style improvements (with pylint)
#
# To Do:
# -
#
###############################################################################

from time import time

###############################################################################
# Sensor class - Sensor and plant data and methods
###############################################################################
class Sensor:
    # pylint: disable=too-many-instance-attributes
    """
    This is a class for sensor data, plant specific limits and all the rest.

    Attributes:
        General:
        --------
        name (string):      sensor name
        pump (int):         pump serving this plant
        tstamp (float):     timestamp of last sensor data reception
        plant (string):     name of the plant assigned to this sensor
        batt_min (int):     minimum battery level [%]
        _tout (float):      max. time between data updates
        valid (bool):       sensor data is valid

        Actual sensor values:
        ---------------------
        temp (float):       temperature [°C]
        cond (int):         conductivity [µS/cm]
        moist (int):        moisture [%]
        light (int):        light [lux]
        batt (int):         battery [%]

        Lower limits (desired by the plant):
        ------------------------------------
        temp_min (float):   temperature [°C]
        cond_min (int):     conductivity [µS/cm]
        moist_lo (int):     moisture (inner limit) [%]
        moist_min (int):    moisture (outer limit) [%]
        light_min (int):    light [lux]

        Upper limits (desired by the plant):
        ------------------------------------
        temp_max (float):   temperature [°C]
        cond_max (int):     conductivity [µS/cm]
        moist_hi (int):     moisture (inner limit) [%]
        moist_max (int):    moisture (outer limit) [%]
        light_max (int):    light [lux]
        light_irr (int):    light [lux], limit for irr_duration
    """
    def __init__(self, sensor_name, tout, batt_min):
        """
        The constructor for Sensor class.

        Parameters:
            sensor_name (string): Sensor name
            tout (float):         max. time between data updates
            batt_min (float):     low battery warning level [%]
        """
        # General
        self.name = sensor_name
        self.pump = 0
        self.tstamp = 0
        self.plant = "<undefined>"
        self.batt_min = batt_min
        self._tout = tout
        # Actual sensor values
        self.temp = 0.0
        self.cond = 0
        self.moist = 0
        self.light = 0
        self.batt = 0
        # Lower limits
        self.temp_min = 0.0
        self.cond_min = 0
        self.moist_lo = 0
        self.moist_min = 0
        self.light_min = 0
        # Upper limits
        self.temp_max = 0.0
        self.cond_max = 0
        self.moist_hi = 0
        self.moist_max = 0
        self.light_min = 0
        self.light_irr = 0
        self.light_max = 0
        # Comparison results
        self.batt_ul = False
        self.temp_ul = False
        self.temp_oh = False
        self.cond_ul = False
        self.cond_oh = False
        self.moist_ul = False
        self.moist_ll = False
        self.moist_hl = False
        self.moist_oh = False
        self.light_ul = False
        self.light_il = False
        self.light_oh = False

    def init_plant(self, plant, pump,
                   temp_min, temp_max,
                   cond_min, cond_max,
                   moist_lo, moist_hi,
                   moist_min, moist_max,
                   light_min, light_irr, light_max):
        """
        Initialize plant data

        Parameters:
            plant (string):     name of the plant assigned to this sensor
            pump (int):         pump serving this plant
            temp_min (float):   temperature [°C]
            temp_max (float):   temperature [°C]
            cond_min (int):     conductivity [µS/cm]
            cond_max (int):     conductivity [µS/cm]
            moist_lo (int):     moisture (inner limit) [%]
            moist_hi (int):     moisture (inner limit) [%]
            moist_min (int):    moisture (outer limit) [%]
            moist_max (int):    moisture (outer limit) [%]
            light_min (int):    light [lux]
            light_irr (int):    light [lux]
            light_max (int):    light [lux]
        """
        # pylint: disable=too-many-arguments
        self.plant = plant
        self.pump  = pump
        self.temp_min = temp_min
        self.temp_max = temp_max
        self.cond_min = cond_min
        self.cond_max = cond_max
        self.moist_lo = moist_lo
        self.moist_hi = moist_hi
        self.moist_min = moist_min
        self.moist_max = moist_max
        self.light_min = light_min
        self.light_irr = light_irr
        self.light_max = light_max

    @property
    def timeout(self):
        """Check sensor data for timeout"""
        return (time() - self.tstamp) > self._tout

    def update_sensor(self, temp, cond, moist, light, batt):
        """
        Update sensor data, timestamp and comparison flags

        Parameters:
            temp (float):     temperature [°C]
            cond (int):       conductivity [µS/cm]
            moist (int):      moisture [%]
            light (int):      light [lux]
            batt (int):       battery [%]
        """
        # pylint: disable=too-many-arguments
        self.temp = temp
        self.cond = cond
        self.moist = moist
        self.light = light
        self.batt = batt
        self.tstamp = time()
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

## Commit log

2021-05-31 Add files via upload
    Schematic and breadboard designed with fritzing V0.9.4 (see www.fritzing.org)
    [flora_breadboard_rev05.fzz]
2021-05-31 Add files via upload
    Pinout (OpenDocument Spreadsheet)
    [RPi_modB_pinout_flora.ods]
2021-05-31 Delete 09_hardware directory
    moved to 08_hardware
    [RPi_modB_pinout_flora.ods, flora_breadboard_rev05.fzz]
2021-06-08 Added support for 2nd pump
2021-06-08 Added support of 2nd pump
2022-10-10 Fixed initialization of irr_rest
    [settings.py]
2023-02-04 Coding style improvements and bugfixes
    [flora.py]

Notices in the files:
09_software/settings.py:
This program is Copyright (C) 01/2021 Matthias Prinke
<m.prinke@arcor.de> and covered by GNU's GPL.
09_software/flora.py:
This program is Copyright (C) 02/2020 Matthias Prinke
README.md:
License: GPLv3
